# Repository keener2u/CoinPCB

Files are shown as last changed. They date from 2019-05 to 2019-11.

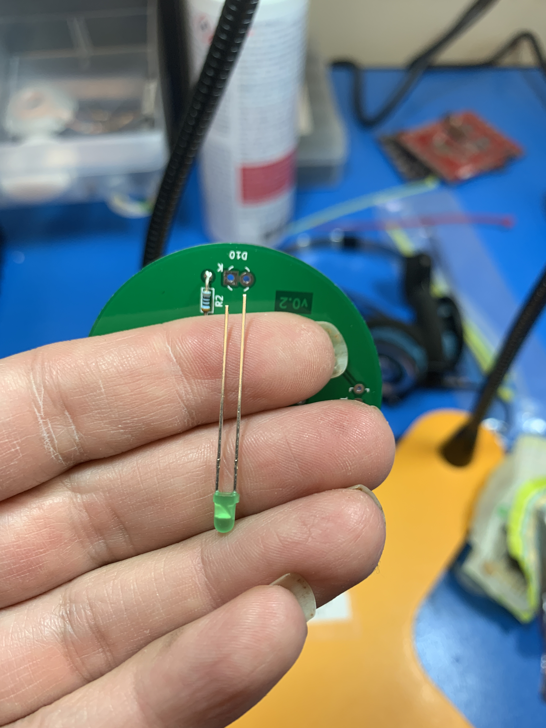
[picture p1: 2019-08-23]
pics/build-steps/Step7.JPG

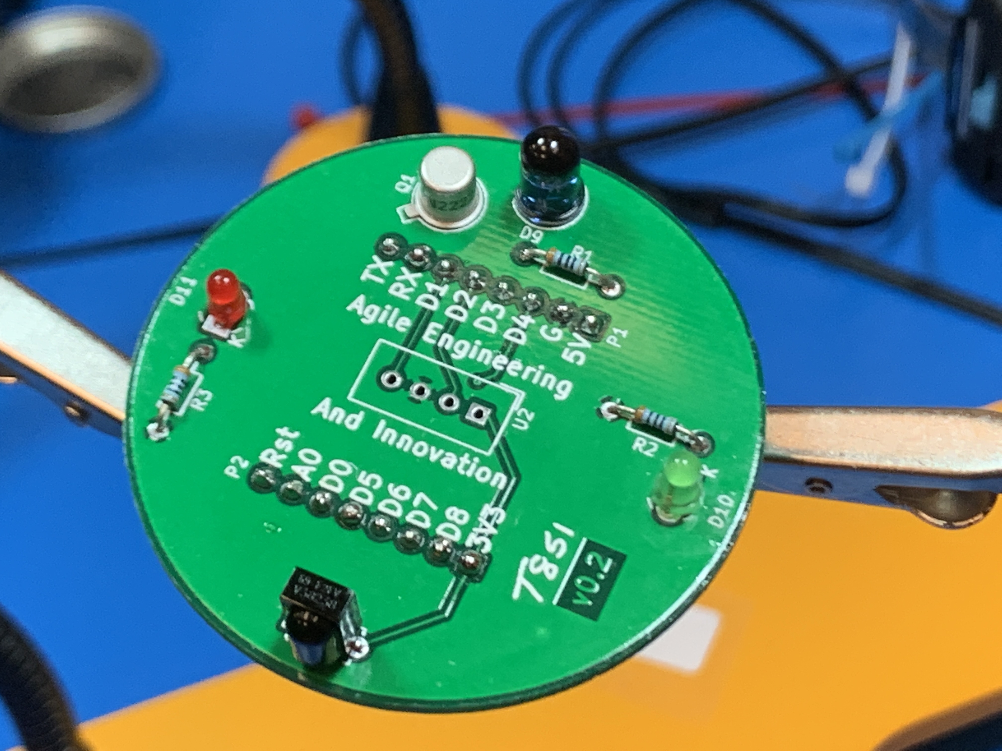
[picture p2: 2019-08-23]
pics/build-steps/Step15.JPG

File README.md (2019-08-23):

# CoinPCB
Simple Coin Shaped ESP8266 Breakout Board
# V0.2 Errata
 * pins D3,D4,D8 are used for chip bootup to figure out where to run the program from . This causes issues if the Coin is hooked into the board on bootup. 
 * D3,D4 also include a pull up resistor on boot and must be rerun to allow the pins to run to low when turned on.
 * simple work around is to not solder Q1
 * advanced is to exacto knife the D3 trace and run a jumper wire from the D3 pin to the D2 PIN if you aren't going to use the I2C connection. If you do this come see me:)
 * reprogram the chip to get it back into a normal state. You can also plug the wifi board into power, let it boot and then plug the coin into the wifi board.
 https://www.reddit.com/r/esp8266/comments/5ujgfl/issue_powering_up_wemos_d1_mini_with_pins_d3_d4/

# V0.2 Updates
 * Fixed V0.1 issues with LED running to power
 * Added 53 Ohm resistor to 5V line through Infrared
 * Created DHT12 I2C symbol package
 * Changed component naming references to start at D9 after input referencs throug D8
# V0.1 Errata

* D1 LED is setup incorrectly on foot print d1 polarization is wrong  
* the infrared transmitter footprint needs to be rotated so the emitter is pointing out on the next rev  
* D3 and D2 LED need to be run to ground instead of power  
* use an exacto knife to cut the traces between 3.3VCC and D3 and Vcc and D4
* use an exacto knife to scrape the top layer off to make the copper ground plane visible, jumper the copper ground plane to the two 100ohm resistors  
* input pin D3 is already on a 1k pull down so there is no need to add another resistor. 
* you can just jumper R1 across the two pads.

# Updates for Next Version
add a spot for a pwm to run a servo
break out the rest of GPIO lines onto the board
add a coincell holder with a power switch

# To Do
Create a how-to on setting up KiCad with the newest symbol and footprint libraries as well as how to import digikey libraries.

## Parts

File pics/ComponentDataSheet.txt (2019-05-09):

https://my.centralsemi.com/get_document.php?cmp=1&mergetype=pd&mergepath=pd&pdf_id=2N2221A.PDF
https://www.digikey.com/products/en/optoelectronics/infrared-uv-visible-emitters/94?k=infrared%20tsal6100
http://www.vishay.com/docs/81009/tsal6100.pdf
https://escapequotes.net/esp8266-wemos-d1-mini-pins-and-diagram/

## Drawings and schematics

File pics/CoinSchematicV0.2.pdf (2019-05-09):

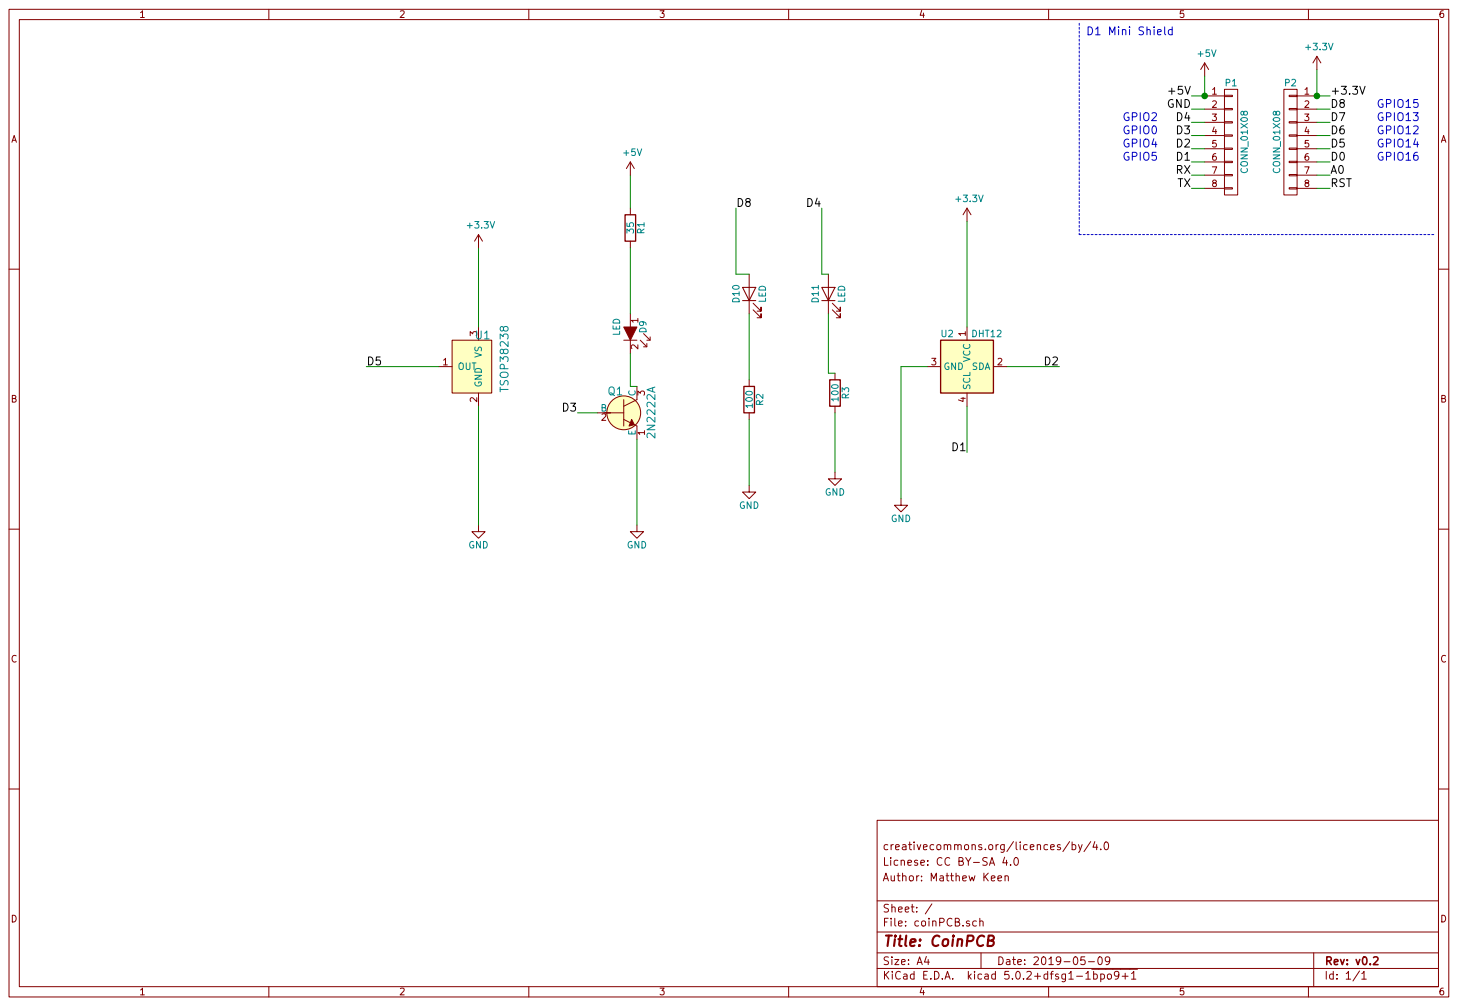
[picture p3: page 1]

creativecommons.org/licences/by/4.0
Licnese: CC BY-SA 4.0
File: coinPCB.sch Sheet: / Author: Matthew Keen

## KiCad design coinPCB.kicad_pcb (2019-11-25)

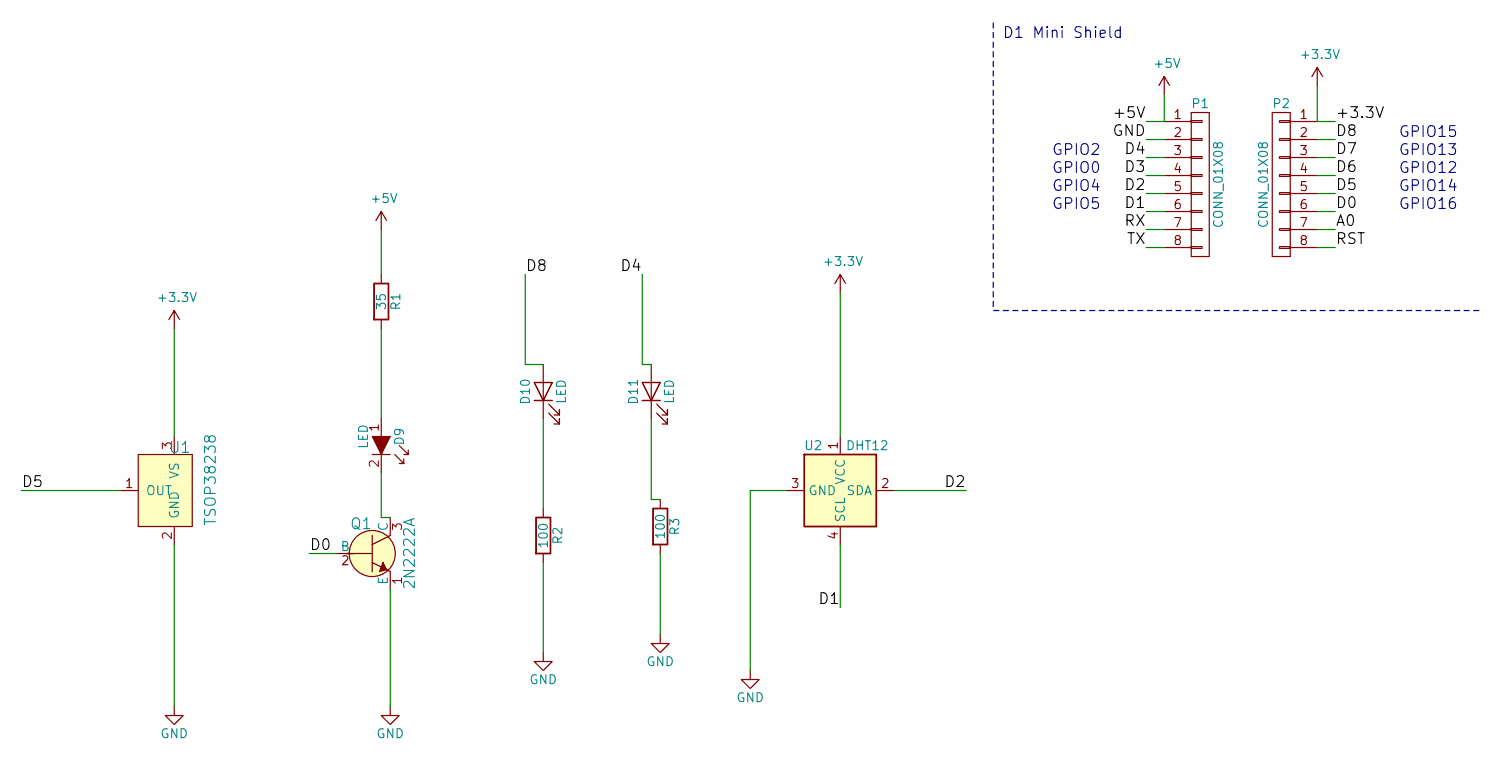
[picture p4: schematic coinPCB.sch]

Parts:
D9: LED; LED_IR_TSAL6100
D10, D11: LED; LED_3mm_Radial
P1, P2: CONN_01X08; D1_mini_Pin_Header
Q1: 2N2222A; TO-18-3; MPN 2N2222A; Digi-Key_PN 2N2222ACS-ND
R1: 35; R_Axial_DIN0204_L3.6mm_D1.6mm_P7.62mm_Horizontal
R2, R3: 100; R_Axial_DIN0204_L3.6mm_D1.6mm_P7.62mm_Horizontal
U1: TSOP38238; IR_Receiver_TSOP38238; MPN TSOP38238; Digi-Key_PN 751-1227-ND
U2: DHT12; Aosong_DHT11_5.5x12.0_P2.54mm

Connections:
+3V3: P2.1, U1.3 (VS), U2.1 (VCC)
+5V: P1.1, R1.1
/A0: P2.7
/D0: P2.6, Q1.2 (B)
/D1: P1.6, U2.4 (SCL)
/D2: P1.5, U2.2 (SDA)
/D3: P1.4
/D4: D11.2 (A), P1.3
/D5: P2.5, U1.1 (OUT)
/D6: P2.4
/D7: P2.3
/D8: D10.2 (A), P2.2
/RST: P2.8
/RX: P1.7
/TX: P1.8
GND: P1.2, Q1.1 (E), R2.2, R3.2, U1.2 (GND), U2.3 (GND)
unnamed: D9.1, R1.2
unnamed: D9.2, Q1.3 (C)
unnamed: D10.1 (K), R2.1
unnamed: D11.1 (K), R3.1

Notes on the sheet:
GPIO2
GPIO0
GPIO4
GPIO5
GPIO15
GPIO13
GPIO12
GPIO14
GPIO16
D1 Mini Shield

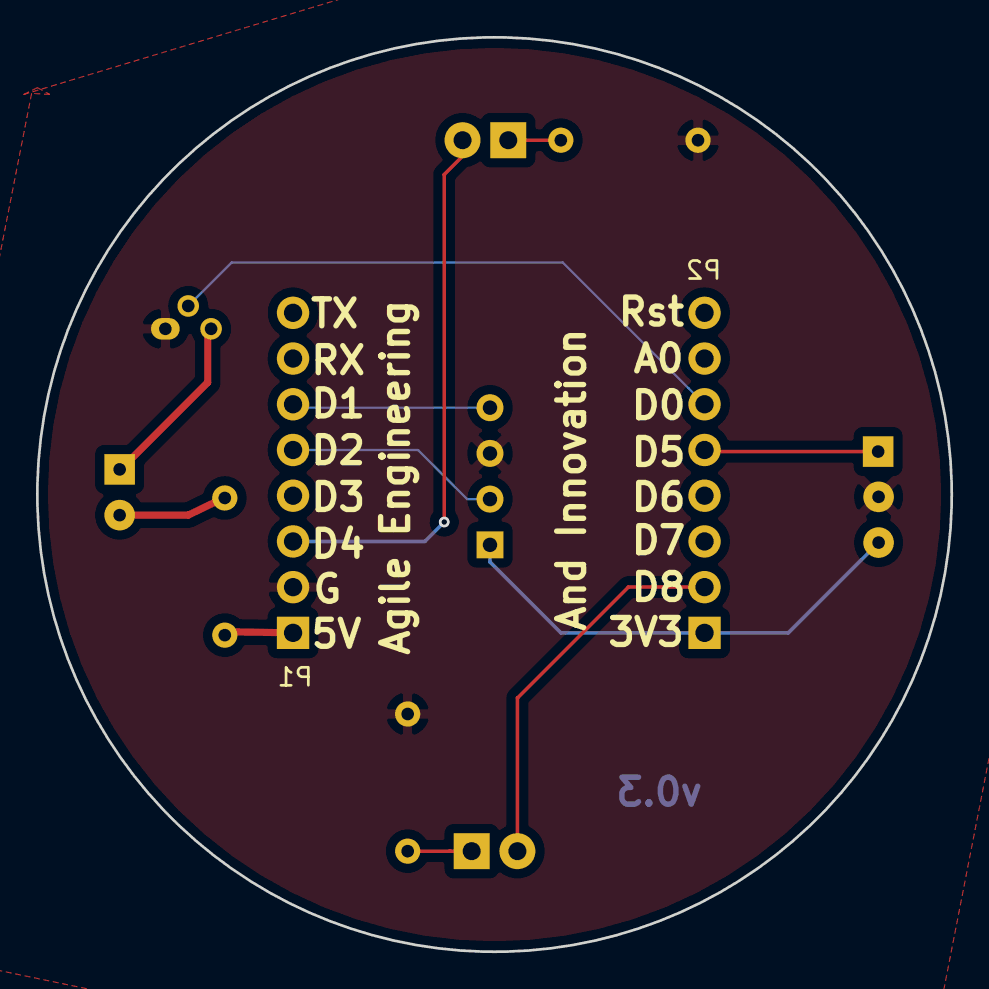
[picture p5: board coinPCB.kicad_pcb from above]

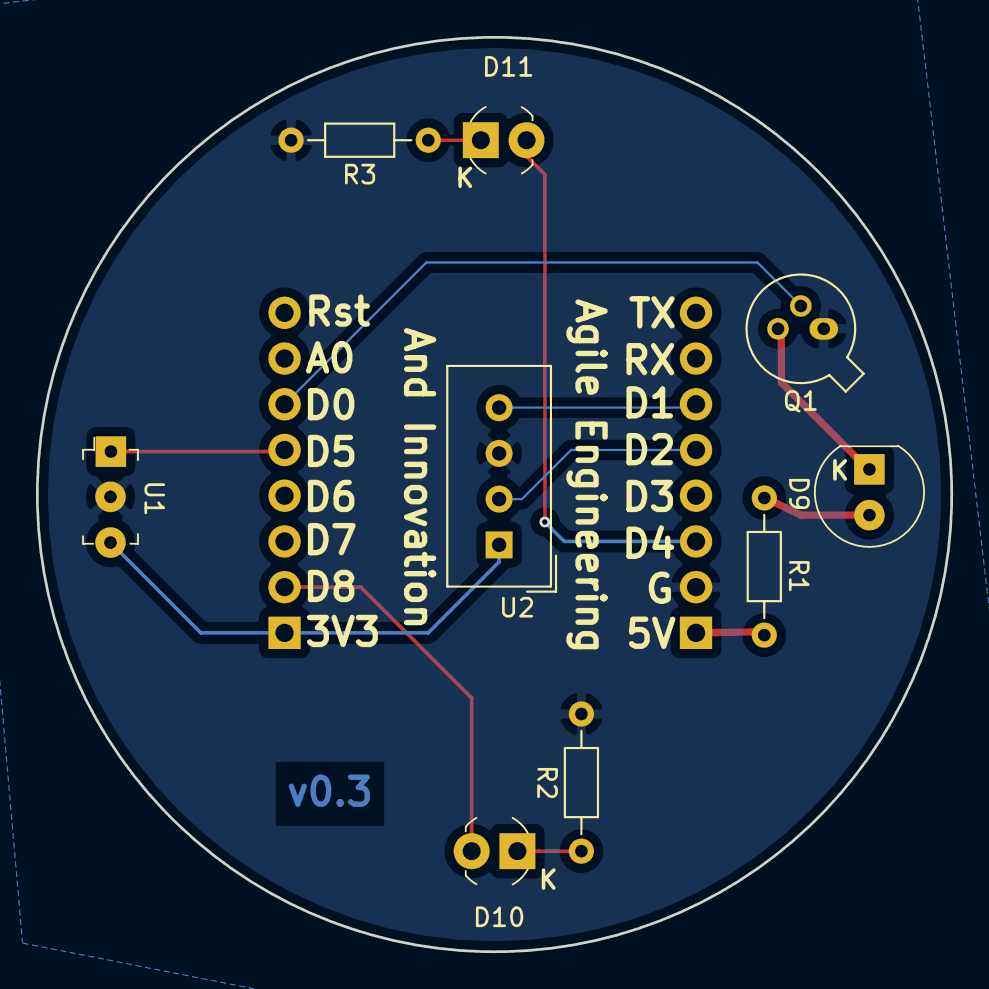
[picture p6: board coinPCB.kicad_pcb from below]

Board: 2 copper layers, 50.8 x 50.8 mm, 11 parts (9 on the bottom side), 13 nets.

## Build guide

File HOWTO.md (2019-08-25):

Git pull 
Setup KiCAD preferably 5.02 or above.
You can do this on a Pixelbook via installing stretch-backport into the Pixelbook Linux Container.

I used the following footprint and symbol librarires. Import these in.
https://github.com/KiCad/kicad-footprints.git
https://github.com/KiCad/kicad-symbols.git 
https://github.com/Digi-Key/digikey-kicad-library.git 

I downloaded the following 3D shapes libraries.

LED_THT.3dshapes
OptoDevice.3dshapes
Package_SO.3dshapes
Package_TO_SOT_THT.3dshapes
Resistor_THT.3dshapes
Sensor.3dshapes

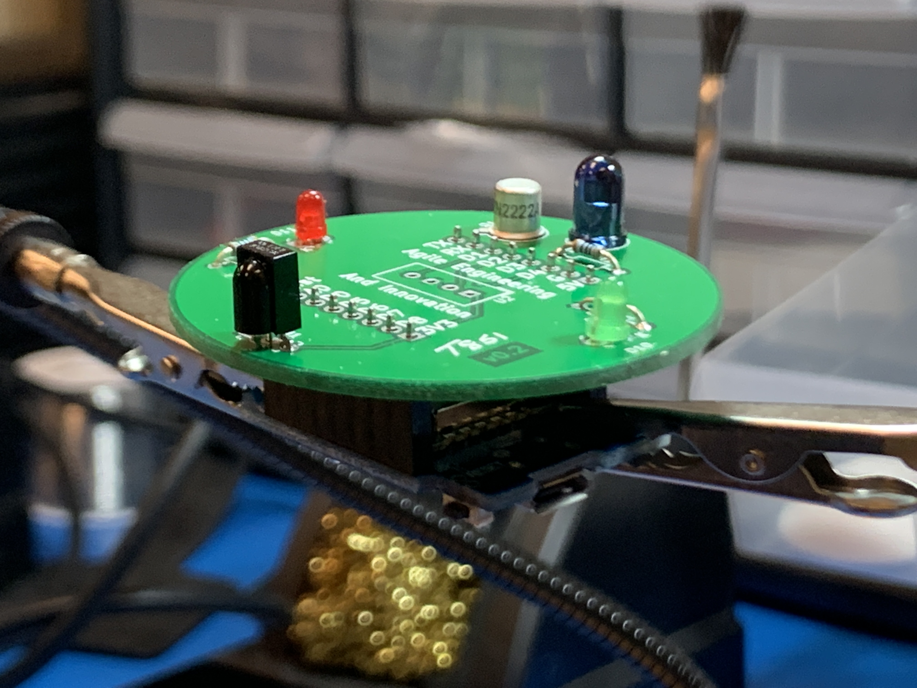
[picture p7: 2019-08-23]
pics/build-steps/Step12.JPG

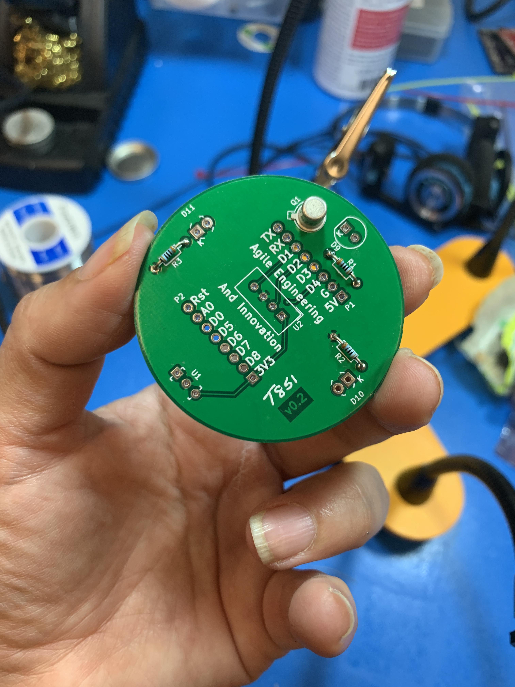
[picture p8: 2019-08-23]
pics/build-steps/Step3.1.JPG

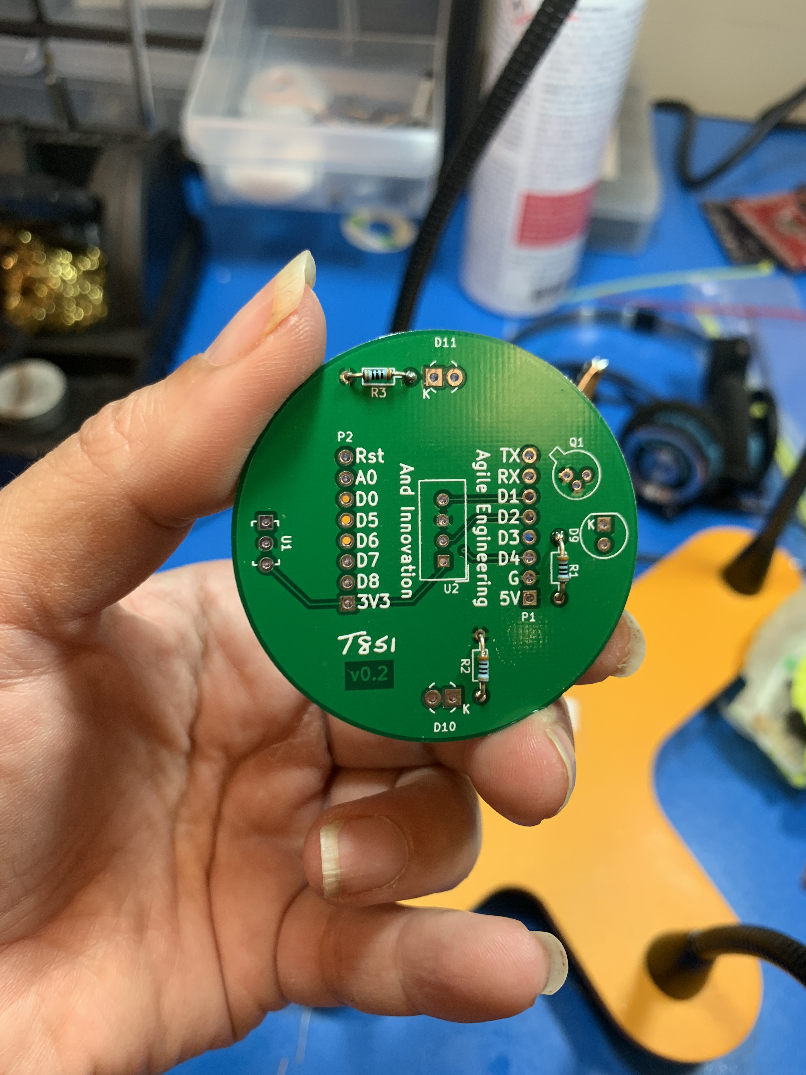
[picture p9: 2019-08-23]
pics/build-steps/Step2.JPG

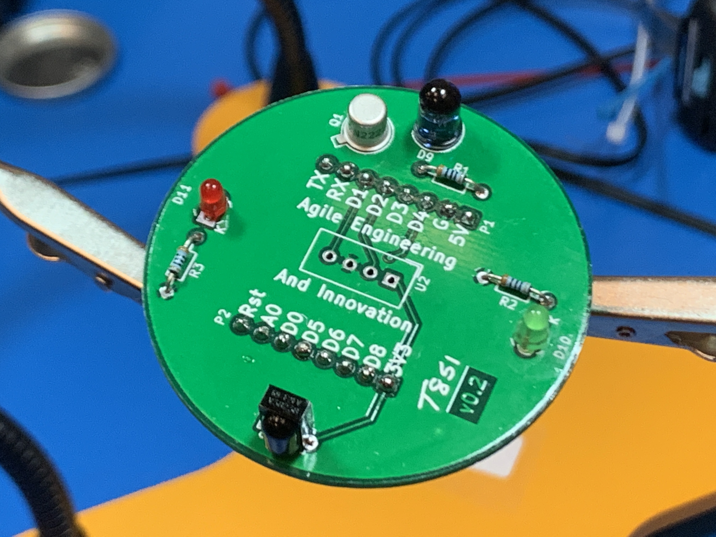
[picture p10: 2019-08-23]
pics/build-steps/Step11.JPG

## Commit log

2019-04-25 first spin v01 includes I2C, 2 LEDS, 1 infrared transmitter and 1 infrared reciever
    [coinPCB-B.Cu.gbr, coinPCB-B.Mask.gbr, coinPCB-B.Paste.gbr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]
2019-04-26 fixed DHT11 symbol on schematic, need to update to DHT12 when I find it
2019-05-03 added DHT12 symbol to project lib. Still uses DHT11 footprint
    [coinPCB.sch]
2019-05-03 updated symbols to new KiCad Library and digikey library
    [coinPCB.sch]
2019-05-03 fixed all errors and should build correctly
    [coinPCB.kicad_pcb, coinPCB.sch]
2019-05-03 fixed schematic errors, including taking out 1k resitor from D3 because that pin as pull-up resistor arleady, and running D4 and D8 to ground
    [coinPCB.kicad_pcb, coinPCB.sch]
2019-05-03 began laying out v0.2 with digikeyfootprins
    [coinPCB.kicad_pcb, coinPCB.sch]
2019-05-03 finished initial PCB trace layout and added the copper backplane as well as fixed the digi-key model of the IR_LED_TSAL_6100 to have the Cathode be the square pad.
    [coinPCB.kicad_pcb, coinPCB.sch]
2019-05-03 added v0.2 draft with 3d model of components on top
    [coinPCB.kicad_pcb]
2019-05-08 added final resitor values to 5v line
    [coinPCB.kicad_pcb, coinPCB.sch]
2019-05-08 updated gerber files and sent to manufacturing. SHIP IT
    [coinPCB-B.Cu.gbr, coinPCB-B.Mask.gbr, coinPCB-B.Paste.gbr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]
2019-05-09 updated PDF schematic and fixed library symbol pointer in KiCAD
    [coinPCB.sch]
2019-08-23 Moved over IR TX pin to D0 because of issues with D3 Pull-up at boot time.
    [_saved_coinPCB.sch, coinPCB.kicad_pcb]
2019-08-25 v0.3 update with gbr files
    [coinPCB-B.Cu.gbr, coinPCB-B.Mask.gbr, coinPCB-B.Paste.gbr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]
2019-08-26 updating ignore to not keep cached save files
    [_saved_coinPCB.sch]
2019-11-25 finalized moving footprint and symbol libraries to shared place to work with the KiCAD Dockerfile.
    [coinPCB.kicad_pcb, coinPCB.sch]

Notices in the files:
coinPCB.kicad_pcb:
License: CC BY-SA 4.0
